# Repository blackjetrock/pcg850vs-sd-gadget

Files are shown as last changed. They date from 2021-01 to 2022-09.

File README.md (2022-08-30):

# pcg850vs-sd-gadget
Gadget for the PC-G850VS family of pocket computers

This gadget:

1. Reads SD card files into memory and then sends them to the PCG850VS
2. Captures data from the PCG850VS and allows it to be written to the SD card
3. Can scope the PIO mod eoutputs of the PC-G850VS

The PCB uses a blue pill as a processor, and an SD card module for the SD card functions. An OLED display allows operatin away from a computer.

Limitations:

The data sent or received is stored in the RAM of the blue pill, so no files greater than the available RAM can be sent or received. 
The SIO protocol has handshaking so this could be used to pause data from the PC-G850VS to the gadget when writing to the SD card. Reading from the card 
could be done without a problem as data is sent once it is read.

An ARM chip with more RAM could be fitted to the blue pill, this is more involved as it requires desoldering the QFP and putting a new one on.

An issue with early code meant that the SD card may not initialise properly. A code fix for this has bee pushed to the repository.

File Tags
---------

If the gadget detects a tag of '@file' (case sensitive) in the file that it has read from the G850 then it usd the filename specified after the tag
(delimited with a space) as the name to use if the file is written to the SD card. If the file tag does not exist then the gadget uses unique
filenames of the form PCGnnnn.DAT where nnnn is chosen to be the next unused value on the SD card.

Circuit
-------

The circuit uses a blue pill to do the processing. The PC-G850VS 11 pin interface is protected by series resistors. Power can come from either the blue pill or the PC-G850VS. If powered by the PC-G850VS short JP1. If you power the gadget from the blue pill when this is shorted then the 5V will be sent into the 5V of the 11 pin interface. I'm not sure what this will d, but it's probably not good.
There's an OLED display that is used to display menus. It is an I2C device. The SD card is held in a catalex SD card module, these are common on ebay.
Three keyswitches are used to control the menu system. As well as the OLED menus there are some commands that can be sent over the USB to serial connection. This needs a USB to serial adapter on J2.

The circuit involving Q1 is an inverter that should allow the UART functionality of the ARM processor to decode the serial data from the PC-G850VS. The current sketch does not use this but rather decodes the data stream using firmware.

For programming I use a STLINK V2 clone from ebay connected to the programming connector of the blue pill.

Construction Notes
==================

Components are fitted as shown on the schematic, apart from a few noted here:

The SD card reader module should be powered from 5V, not 3V3. The PCBs all have a 3V3 supply wired to the module. I have found that some modules will work with a 3V3 supply, but some won't. Cutting the track to the power pin of the module and running  wire from 3V3 to the supply pin of the module fixes the problem.

R14, Q1 and R15 are a hardware level shifter that takes the transmitted data (TX) from the PC-G850VS and sends it to the hardware USART on the blue pill. I don't use this at the moment as the code can decode the serial data. These components can be omitted or fitted. The sketch will have to be adjusted if you want to use the hardware USART.

J7 is a power jumper. If it is shorted then power comes from the PC-G850VS. If open then the blue pill can power the circuit (useful if programming the blue pill).
R4 and R5 are power connections and should be 0R links or wire links.

The blue pill, display and SD card reader can either be soldered to the PCB or fitted in sockets. If soldered then th eprofile is much lower but obviously these parts are harder to remve if you need to.

The SD card reader comes with a right angle type connector, for fitting on the PCB I desolder the connector it comes with and fit a straight connector.

I use a straight pin header for J1 and solder it on the top of the board. This is because straight headers are cheaper and they also lead to a lower profile once fitted.

OLED displays come in two pinouts, with reversed power connections. There's two connectors for the OLED display, one for each pinout. Make sure the OLED display is connected to the correct pinout connector.

I use an ST-LINKV2 from ebay for programming the blue pill. Any method of getting the sketch on to the blue pill should be fine.

Code
----

The menu structure that the code uses varies with the version of code that is running and th efunctions that are added to the code.
The menu option names have been elaborated from th ebasic names given in the instruction sheet, but it should be possible to work out 
which option does what.

Supported Devices
-----------------

The gadget has been used on the:
PC-G850VS
PC-G850

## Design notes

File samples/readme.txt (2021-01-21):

Sample Files
============

BASEN.BAS   This is the BASE-N program that executes when the BASE-N
            key is pressed.

picpro.asm  PIC program that runs on the prototype PCB and flashes the LED.

SCOPEDEMO.DAT A BASIC program that writes 0 to 255 to the PIO port. This
	      can be used to exercise the PIO scope option of the SD card
	      gadget. Set PIO mode and Scope PIO and then run this program.

ROMRD3.DAT    A BASIC program that attempts to read a 93C56 EEPROM.
	      Unfortunately it doesn't work.

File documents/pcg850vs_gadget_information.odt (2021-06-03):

Sharp PC-G850VS Gadget

# Overview

This gadget attached to the 11 pin socket on the PC-G850Vs and allows data sent over the serial data connection to be stored on SD cards. Files on the SD card can also be sent to the PC-G850VS. This provides a non-volatile storage system for the P-G850VS, and also a way to transfer files from a PC to the P-G850VS that doesn’t rely on a serial cable of some sort.

The PC-G850VS 11 pin connector is actually a versatile port that can operate in a number of modes. The gadget handles two of these modes:

SIO mode

PIO Mode

SIO mode is used for file transfer.

In PIO mode the gadget can display the state of the digital lines when set as outputs on the PC-G850VS as either a line graph or a number. To make some use of these signals, the firmware of the gadget would have to be adjusted. The soure code is available on GitHub.

There is an English manual available on the internet for the PC-G850VS, this contains information about the 11 pin interface.

# Gadget Hardware

The gadget is based around a ‘Blue Pill’ board. This is a small PCB with an STM32F103C8 microcontroller on it. It is programmed using the Arduino IDE. The STLINK V2 USB programming adapter is used to download code to the microcontroller.

Attached to the STM32F103C8 is an SD card adapter. The firmware reads and writes text to and from files on this SD card into a buffer in the microcontrollers RAM. This buffer of fixed size and this limits the largest file that can be transferred. This limit could be removed if the handshaking is enabled on the Sio interface, the code does not use this at present.

There is a small prototype area on the PCB that can be used to add hardware to the microcontroller, that can then be driven by the PC-G850.

An OLED display is used to display a menu system and also data from files and status messages.

Three buttons are used to control the menu and information screens. The red button is an ENTER, the black and white buttons are UP and DOWN.

# Jumper J7

The 11 pin interface can power the gadget, or it can be powered from the USB port on the Blue Pill. The best power option when attached to the PC-G850 is the 11 pin interface, there is no danger of feeding USB power into the 5V supply of the PC-G850, which could damage it, but this does put an extra load on the batteries in the PC-G850. Jumper J7 controls the connection of power to the gadget:

J7 with jumper in position: gadget powered from PC-G850

J7 with no jumper: gadget powered from Blue Pill USB

Do not operate the gadget with the USB attached and the jumper in position. This will connect the 5V from the Blue Pill to the 5V on the 11 pin interface and could damage the PC-G850.

# Gadget Firmware

The gadget firmware is in the github repository:

https://github.com/blackjetrock/pcg850vs-sd-gadget

It uses the Arduino IDE and framework. Programming is done using an STLINK V2 dongle attached to the programming connections on the Blue Pill. Power is not connected and the Blue Pill is powered from either the gadget or, preferable when programming, from USB. The STLINK V2 doesn’t have a large power supply capability and the gadget probably takes too much power when the OLED display is displaying a large number of pixels.

# Gadget Startup

On startup (or reset) the gadget checks the SD card and displays either ‘SD OK’ if a working card is found, or ‘SD Fail’ if no card is found. Obviously, if SD Fail is displayed then no files can be read or written, but all other functions will work.

# Gadget Menu

# Transferring a file to the SD card

The gadget is always ready to receive data from the 11 pin interface. Before sending a file to the gadget:

Put whatever file is required to be sent in the TEXT buffer. (This can be done using the TEXT mode options such as Basic->Text)

Set SIO mode on the gadget

(‘SIO’ menu option)

(‘Set SIO Mode’ menu option)

Clear the receive buffer in the gadget

(‘Clear’ menu option)

Set the correct SIO parameters in the PC-G850

These are:

(‘TEXT’ button)

(‘Sio’ option)

(‘Format’ option)

(‘baud rate’ 9600)

(‘data bit’ 8)

(‘stop bit’ 1)

(‘parity’ none)

(‘end of line’ CR LF)

(‘end of file’) 1A

(‘line number’ yes)

(‘flow’ none)

Use Sio menu to send the file

(‘TEXT’ button)

(‘Sio’ option)

(‘Save’ option)

When transfer completes, the contents of the buffer can be displayed

(‘Display’ menu option)

The bytes of the buffer should be displayed in ASCII and hex. UP and DOWN to page the data and the RED button to exit

Write the buffer to the SD card

(‘Write’ menu option)

The filenames are automatically chosen by the gadget. You can rename them in a computer if needed. The gadget doesn’t have the capability to rename files at present. The files are written to the root directory of the SD card.

The name of the file written and the number of bytes written are displayed for a few seconds

# Transferring a file from the SD card

Set SIO mode on the gadget

(‘SIO’ menu option followed by ‘Set SIO Mode’)

SIO mode only needs to be set once. It remains in force until another mode (such as PIO mode) is set.

List the files and select the one to send to the PC-G850.

(‘List’ menu option)

UP and DOWN are used to select the filename of the file to read. This menu option does not read the file, it just selects the file by name.

Clear the buffer

(‘Clear’ menu option)

Read the file

(‘Read’ menu option)

The name of the file and number of bytes read are dispolayed for a second or two. (There is a strange problem that sometimes happens whereby the number of byte read is 1. If this happens, read the file again).

Set the SIO parameters on the PC-G850 as above.

This only needs to be done once on the PC-G850, it retains SIO settings while off. A reset of the PC-G850 may reset the settings.

Set receive mode on the PC-G850

(‘TEXT’ button)

(‘Sio’ option)

(‘Load’ option)

Send the buffer

(‘Send’ menu option)

the file will transfer and the PC-G850 menu should change to the Sio menu. The file that was sent should now be in the TEXT buffer on the PC-G850

# Scoping the PIO outputs

Load the SCOPE.BAS example program into the PC-G850 TEXT buffer. This program counts in binary on the PIO outputs of the PC-G850.

Set PIO mode on the gadget, and GPIOs to all be inputs

(‘PIO’ menu option)

(‘PIO All Inputs’ menu option)

Enter run mode on the PC-G850

Select the Scope PIO menu option on the gadget just before RUNing the BASIC program.

(‘PIO’ menu option)

(‘Scope PIO’ menu option)

You should see the PIO lines counting in binary.

The RED button starts a new trace. There is no trigger facility and the GPIO lines are only sensed as high or low, not as analogue values. The UP and DOWN keys exit.

# Example Files

The githib repository has a directory that contains example files. If these are place don an SD card that is then inserted into the gadget, they can be used as a starting point for using the gadget.

# Supported Machines

I have used the gadget on these machines:

PC-G850VS

PC-G850V

It may work on other variants of the PC-G850 series, please let me know if you have tried other variants.

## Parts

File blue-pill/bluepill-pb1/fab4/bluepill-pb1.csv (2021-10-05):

Id | Designator | Package | Quantity | Designation | Supplier and ref
1 | J6 | PinHeader_1x06_P2.54mm_Vertical | 1 | Conn_01x06
2 | J7 | PinHeader_1x02_P2.54mm_Vertical | 1 | Conn_01x02
3 | R17,R16,R3,R2,R1 | R_Axial_DIN0207_L6.3mm_D2.5mm_P7.62mm_Horizontal | 5 | 4k7
4 | TP1 | TestPoint_Loop_D2.60mm_Drill0.9mm_Beaded | 1 | TestPoint
5 | R15,R14 | R_Axial_DIN0207_L6.3mm_D2.5mm_P7.62mm_Horizontal | 2 | R_Small
6 | U1 | BLUEPILL | 1 | BP
7 | SW2,SW3,SW1 | SW_PUSH-12mm | 3 | Switch_SW_SPST
8 | J5 | PinHeader_1x09_P2.54mm_Vertical | 1 | Conn_01x09
9 | Q1 | TO92_vert | 1 | Q_NPN_CBE
10 | J4,J2,J3 | PinHeader_1x04_P2.54mm_Vertical | 3 | Conn_01x04
11 | J1 | PinHeader_1x11_P2.54mm_Vertical | 1 | pc850vs_11_pin
12 | R13,R12,R11,R10,R9,R8,R7,R6,R5,R4 | R_Axial_DIN0207_L6.3mm_D2.5mm_P7.62mm_Horizontal | 10 | 1k
13 | A1 | SD_Card_Module | 1 | SD_Card_Module_catalex

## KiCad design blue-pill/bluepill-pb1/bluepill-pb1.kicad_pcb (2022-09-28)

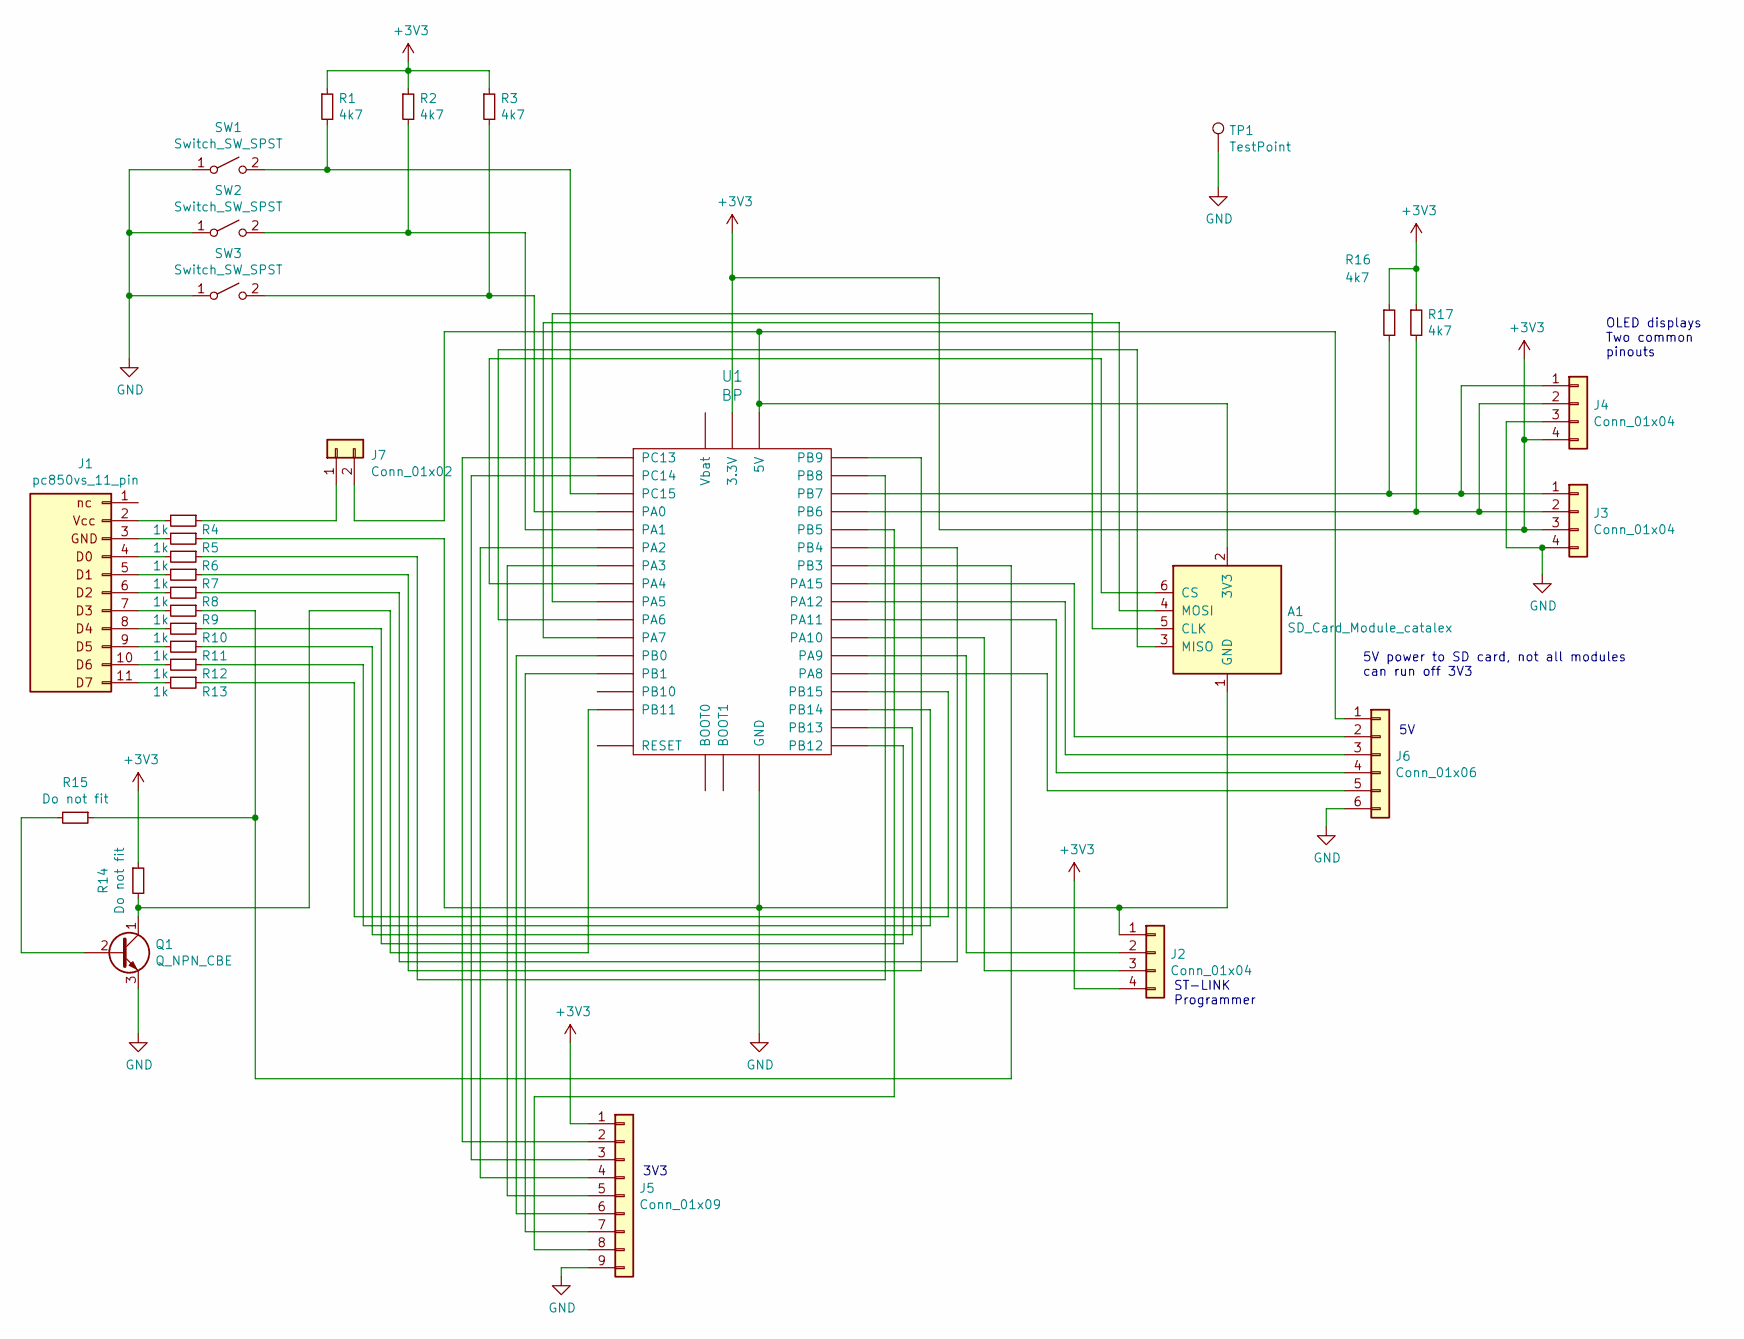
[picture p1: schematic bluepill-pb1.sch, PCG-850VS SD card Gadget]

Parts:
A1: SD_Card_Module_catalex; SD_Card_Module
J1: pc850vs_11_pin; PinHeader_1x11_P2.54mm_Vertical
J2, J3, J4: Conn_01x04; PinHeader_1x04_P2.54mm_Vertical
J5: Conn_01x09; PinHeader_1x09_P2.54mm_Vertical
J6: Conn_01x06; PinHeader_1x06_P2.54mm_Vertical
J7: Conn_01x02; PinHeader_1x02_P2.54mm_Vertical
Q1: Q_NPN_CBE; TO92_vert
R1, R2, R3, R16, R17: 4k7; R_Axial_DIN0207_L6.3mm_D2.5mm_P7.62mm_Horizontal
R4, R5, R6, R7, R8, R9, R10, R11, R12, R13: 1k; R_Axial_DIN0207_L6.3mm_D2.5mm_P7.62mm_Horizontal
R14, R15: Do not fit; R_Axial_DIN0207_L6.3mm_D2.5mm_P7.62mm_Horizontal
SW1, SW2, SW3: Switch_SW_SPST; SW_PUSH-12mm
TP1: TestPoint; TestPoint_Loop_D2.60mm_Drill0.9mm_Beaded
U1: BP; BLUEPILL

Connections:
+3V3: J2.4, J3.3, J4.4, J5.1, R1.1, R2.1, R3.1, R14.1, R16.1, R17.1, U1.3V3 (3.3V)
GND: A1.1 (GND), J2.1, J3.4, J4.3, J5.9, J6.6, Q1.3 (E), R5.1, SW1.1 (A), SW2.1 (A), SW3.1 (A), TP1.1, U1.G (GND)
unnamed: A1.2 (3V3), J6.1, J7.2, U1.5V
unnamed: A1.3 (MISO), U1.PA6
unnamed: A1.4 (MOSI), U1.PA7
unnamed: A1.5 (CLK), U1.PA5
unnamed: A1.6 (CS), U1.PA4
unnamed: J1.2 (+5V), R4.2
unnamed: J1.3 (GND), R5.2
unnamed: J1.4 (D0), R6.2
unnamed: J1.5 (D1), R7.2
unnamed: J1.6 (D2), R8.2
unnamed: J1.7 (D3), R9.2
unnamed: J1.8 (D4), R10.2
unnamed: J1.9 (D5), R11.2
unnamed: J1.10 (D6), R12.2
unnamed: J1.11 (D7), R13.2
unnamed: J2.2, U1.PA9
unnamed: J2.3, U1.PA10
unnamed: J3.1, J4.1, R16.2, U1.PB7
unnamed: J3.2, J4.2, R17.2, U1.PB6
unnamed: J5.2, U1.PC13
unnamed: J5.3, U1.PC14
unnamed: J5.4, U1.PA2
unnamed: J5.5, U1.PA3
unnamed: J5.6, U1.PB0
unnamed: J5.7, U1.PB1
unnamed: J5.8, U1.PB5
unnamed: J6.2, U1.PA15
unnamed: J6.3, U1.PA12
unnamed: J6.4, U1.PA11
unnamed: J6.5, U1.PA8
unnamed: J7.1, R4.1
unnamed: Q1.1 (C), R14.2, U1.PB11
unnamed: Q1.2 (B), R15.2
unnamed: R1.2, SW1.2 (B), U1.PC15
unnamed: R2.2, SW2.2 (B), U1.PA1
unnamed: R3.2, SW3.2 (B), U1.PA0
unnamed: R6.1, U1.PB8
unnamed: R7.1, U1.PB9
unnamed: R8.1, U1.PB4
unnamed: R10.1, U1.PB12
unnamed: R11.1, U1.PB13
unnamed: R12.1, U1.PB14
unnamed: R13.1, U1.PB15
unnamed: R9.1, R15.1, U1.PB3

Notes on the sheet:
ST-LINK Programmer
OLED displays Two common pinouts
3V3
5V power to SD card, not all modules can run off 3V3

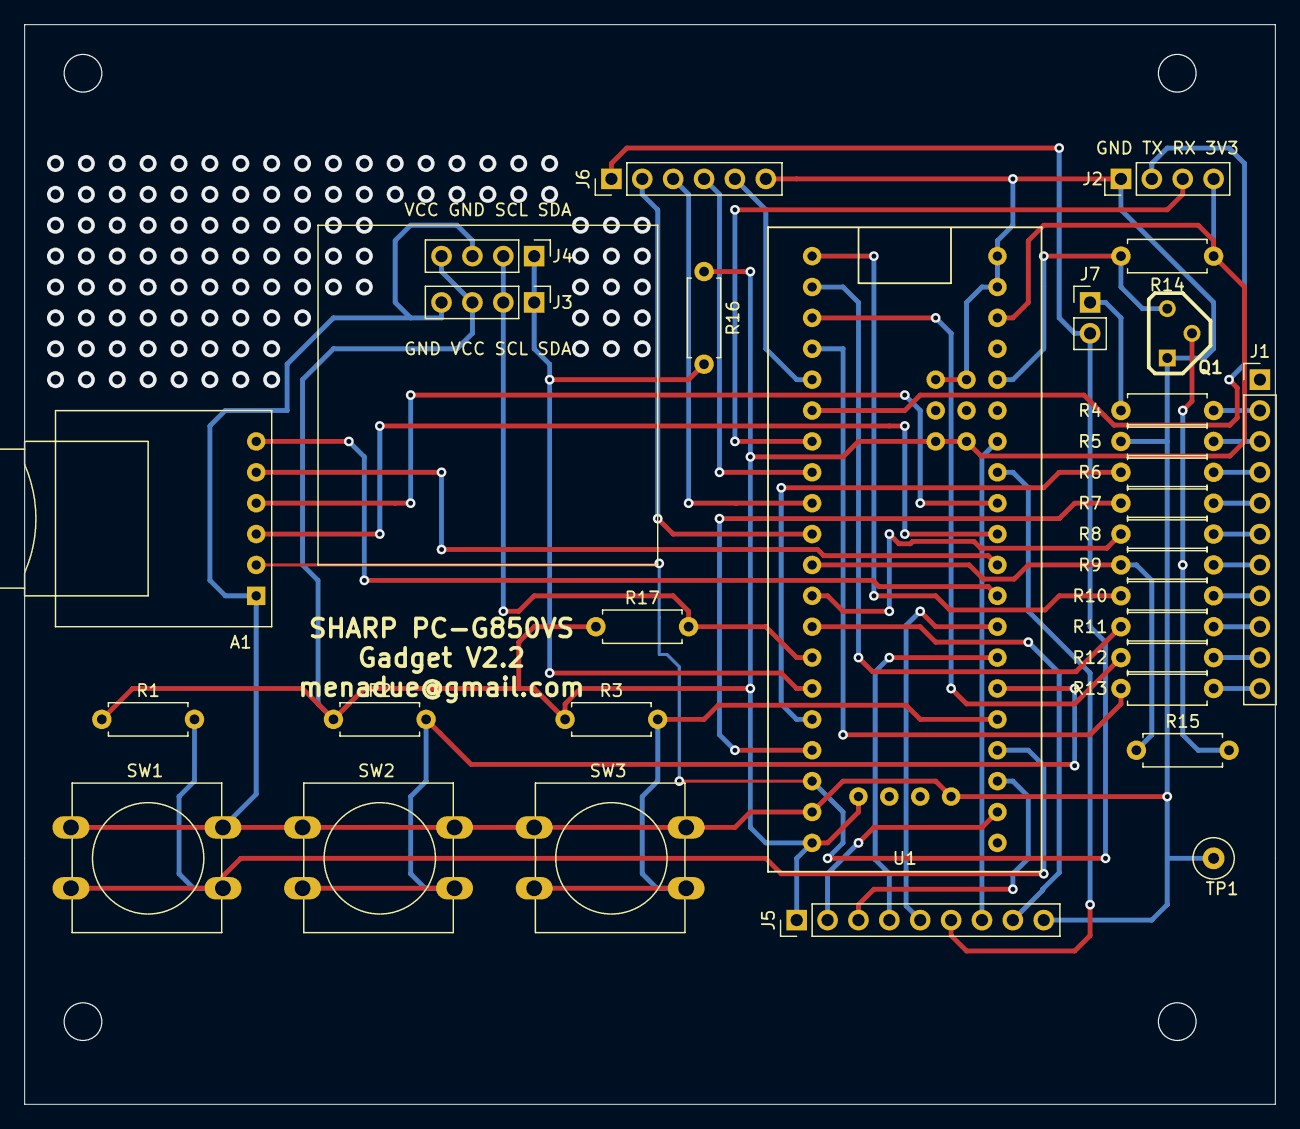
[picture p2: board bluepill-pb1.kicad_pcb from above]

Board: 2 copper layers, 102.9 x 88.8 mm, 31 parts (0 on the bottom side), 46 nets.

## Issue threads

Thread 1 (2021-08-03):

Would like to buy a build of this device

phoenixx100, 2021-08-03:
Am _very_ interested in purchasing a build of this useful device for a reasonable price, because I lack the hardware construction skills.

Please, contact me at:

phoenixx100 (at) hotmail.com

blackjetrock, 2021-08-03:
Hello,

I have just ordered a set of PCBs which should arrive in a couple of weeks
or so. I have a set of documents about the gadget and other bits and bobs.
Due to the current shipping situation I only ship using a tracked service.

Regards

Andrew Menadue

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

phoenixx100, 2021-08-03:
Thanks for your swift reply. Good to hear that you are planning on creating some more of them. What would you be charging for one? Also, would you want my payment in advance?

________________________________
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

blackjetrock, 2021-08-03:
Hi,
An assembled gadget is £27 plus shipping, which is tracked. If you are
interested then I'll build the gadget and then we can arrange payment
including shipping, so no payment until I have a gadget built and ready to
ship.

Regards

Andrew Menadue

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

phoenixx100, 2021-08-03:
Excellent...

I have just today ordered a SHARP PC-G850VS. It will be coming from Japan, so it will surely take some time to arrive here in Chicago. I'm an oldskool 1980s programmer (mostly BASIC and similar languages) and am really interested in learning C and the Assembly languages offered on the PC-G850VS. Having such a small 32K memory, it is unthinkable to begin using it for serious purposes without some sort of mass storage solution.

I am very much looking forward to purchasing and utilizing your device.

Terry

________________________________
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

blackjetrock, 2021-08-07:
Hi,

I have built a gadget for you. I saw that you are in Chicago so worked out
shipping, which is £13. Obviously I'll need a more targeted address than
Chicago!

Regards

Andrew Menadue

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

blackjetrock, 2021-08-07:
Hi,

I have built a gadget for you. I saw that you are in Chicago so worked out
shipping, which is £13. Obviously I'll need a more targeted address than
Chicago!

Regards

Andrew

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

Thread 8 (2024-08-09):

Can you please help? Can you help me when I get the above error when compiling with Arduino?

chunmingwen, 2024-08-09:
Arduino:1.8.19 (Windows 7), 開發板:"Generic STM32F1 series, BlackPill F103C8, STM32CubeProgrammer (SWD), Enabled (generic 'Serial'), None, Low/Full Speed, Smallest (-Os default), None, Newlib Nano (default)"

In file included from C:\Program Files (x86)\Arduino\libraries\Adafruit_Circuit_Playground/utility/CP_Firmata.h:17,

                 from C:\Program Files (x86)\Arduino\libraries\Adafruit_Circuit_Playground/Adafruit_Circuit_Playground.h:25,

                 from C:\Program Files (x86)\Arduino\libraries\Adafruit_Circuit_Playground/Adafruit_CircuitPlayground.h:3,

                 from C:\Users\wencm\Downloads\pcg850vs-sd-gadget-main\pcg850vs_gadget_1\pcg850vs_gadget_1.ino:7:

C:\Program Files (x86)\Arduino\libraries\Adafruit_Circuit_Playground/utility/CP_Boards.h:746:2: error: #error "Please edit CP_Boards.h with a hardware abstraction for this board"

  746 | #error "Please edit CP_Boards.h with a hardware abstraction for this board"

      |  ^~~~~

exit status 1

開發板 Generic STM32F1 series 編譯錯誤。

This report would have more information with
"Show verbose output during compilation"
option enabled in File -> Preferences.

blackjetrock, 2024-08-10:
Hello,
I don't use windows at all, in fact I don't have a windows machine. It may
be that you are attempting to compile with the wrong libraries, can you
check you are using the correct libraries, in that they match the ones I
used ?
Your error looks a bit like you haven't set up the cp_boards.h file for the
blue pill stm32f103c8?

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

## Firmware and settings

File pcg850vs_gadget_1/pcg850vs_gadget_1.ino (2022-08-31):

////////////////////////////////////////////////////////////////////////////
// pcg850vs_gadget_1_Rev_B_v1_2_SBH
//
// Based on https://github.com/blackjetrock/pcg850vs-sd-gadget
// 
// Modified: SBH 04/08/22   v1.0   Added comments
//           SBH 05/08/22   v1.1   Removed surplus code, added transmit status graph
//           SBH 05/08/22   v1.2   Blinking cursor    case TRANSFER_PCU:
//           AJM 21/08/22   v2.0   Merged SBH code, altered version and put back in menu options
//           AJM 22/08/22   v2.1   Tidied version string and menu
//           AJM 27/08/22   v2.2   Added SSIO reception interrupt. Temp comment out due to menu scrolling
//                                 not working.
//           AJM 28/08/22   v2.3   Added 'Send File' menu option. This sends the file data directly from an
//                                 SD card file so has no buffer involved and hence no length limit.
//                                 Re-arranged menus so they always fit on a screen.
//           AJM 31/08/22   v2.4   Has fixed menu scrolling and start of extra modes for data
//                                 transfer
//                                 Added status line
////////////////////////////////////////////////////////////////////////////////////////////////////
//
// ARDUINO IDE SETTINGS
// Board:          Generic STM32F1 Series
// Board Part No.: BlackPill F103C8
// Upload method:  STM32CubeProgrammer (SWD)
// Preferences -> Additional Boards Manager URL: https://github.com/stm32duino/BoardManagerFiles/raw/main/package_stmicroelectronics_index.json
//
///////////////////////////////////////////////////////////////////////////

#define VERSION_STRING "V2.4"

#include <SPI.h>
#include <SD.h>
#include <Wire.h>
#include <Adafruit_GFX.h>
#include <Adafruit_SSD1306.h>

#define SCREEN_WIDTH 128 // OLED display width, in pixels
#define SCREEN_HEIGHT 64 // OLED display height, in pixels

// Declaration for an SSD1306 display connected to I2C (SDA, SCL pins)
#define OLED_RESET     4 // Reset pin # (or -1 if sharing Arduino reset pin)
Adafruit_SSD1306 display(SCREEN_WIDTH, SCREEN_HEIGHT, &Wire, OLED_RESET);

#define ACK1  1
#define ACK2  0       // Works with PCG850

////////////////////////////////////////////////////////////////////////////////////////////////////
//
// Define variables
//
////////////////////////////////////////////////////////////////////////////////////////////////////

int loop_loops = 0;

Sd2Card card;
SdVolume volume;
SdFile root;

int filename_index = 0;

const int chipSelect = 4;

// Pins for Sharp 11 pin interface data lines
const int IFD0Pin  = PB8;
const int IFD1Pin  = PB9;
const int IFD2Pin  = PB4;
const int IFD3Pin  = PB3;
const int IFD4Pin  = PB12;
const int IFD5Pin  = PB13;
const int IFD6Pin  = PB14;
const int IFD7Pin  = PB15;

// SIO pins
const int SIORTSPin = IFD0Pin;
const int SIODTRPin = IFD1Pin;
const int SIORXDPin = IFD2Pin;
const int SIOTXDPin = IFD3Pin;
const int SIOCDPin  = IFD4Pin;
const int SIOCTSPin = IFD5Pin;
const int SIODSRPin = IFD6Pin;
const int SIOCIPin  = IFD7Pin;

// SSIO pins
const int SIOBUSYPin = IFD0Pin;
const int SIODOUTPin = IFD1Pin;
const int SIOXINPin  = IFD2Pin;
const int SIOXOUTPin = IFD3Pin;
const int SIODINPin  = IFD4Pin;
const int SIOACKPin  = IFD5Pin;
const int SIOEX1Pin  = IFD6Pin;
const int SIOEX2Pin  = IFD7Pin;

// Debug outputs
const int statPin   = PC13;
const int dataPin   = PC14;


#define NIF 8

const int if_pin[NIF] = {
  IFD0Pin,
  IFD1Pin,
  IFD2Pin,
  IFD3Pin,
  IFD4Pin,
  IFD5Pin,
  IFD6Pin,
  IFD7Pin,
};
  
File myFile;

// Capture file
File dumpfile;


#define DEBUG_SERIAL 0
#define DIRECT_WRITE 0

// STM32F103C8 has only 20k of SRAM
//const int MAX_BYTES = 10000;
const int MAX_BYTES = 10000; 
const int button1Pin = PA0;
const int button2Pin = PA1;
const int button3Pin = PC15;

typedef unsigned char BYTE;

typedef void (*FPTR)();
typedef void (*CMD_FPTR)(String cmd);

#define NUM_BUTTONS 3

// Debounce
#define MAX_BUT_COUNT 6

int but_pins[NUM_BUTTONS] = {button1Pin, button2Pin, button3Pin};

typedef struct _BUTTON
{
  int     count;
  boolean pressed;
  boolean last_pressed;   // For edge detection
  FPTR    event_fn;
} BUTTON;

BUTTON buttons[NUM_BUTTONS];

enum ELEMENT_TYPE
  {
    BUTTON_ELEMENT = 10,
    SUB_MENU,
    MENU_END,
  };

struct MENU_ELEMENT
{
  enum ELEMENT_TYPE type;
  char *text;
  void *submenu;
  void (*function)(struct MENU_ELEMENT *e);
};


struct MENU_ELEMENT *current_menu;
struct MENU_ELEMENT *last_menu;
struct MENU_ELEMENT *the_home_menu;

unsigned int menu_selection = 0;
unsigned int menu_size = 0;
unsigned int top_scroll = 0;

#define MENU_TOP_LINE 1
#define MAX_LISTFILES 7
#define MAX_NAME      20

const char *filetag = "@file ";

MENU_ELEMENT listfiles[MAX_LISTFILES+1];
int num_listfiles;
char names[MAX_LISTFILES][MAX_NAME];
char selected_file[MAX_NAME+1];
char current_file[MAX_NAME+1];
char current_rx_file[MAX_NAME+1];

// Where the received data goes
char stored_bytes[MAX_BYTES] = "Test data example. 01234567890";

int stored_bytes_index = 0;

// How many bytes in the buffer. We have a default for testing without a Microtan
int bytecount = 24;

////////////////////////////////////////////////////////////////////////////////////////////////////
//
// communication with ISRs
//
////////////////////////////////////////////////////////////////////////////////////////////////////

volatile int data_byte;
volatile int bit_count;
volatile int got_byte = 0;
volatile int state = 0;
volatile int data_bit = 2;

// We build the byte packet in this int, it can be longer than
// 8 bits as it has th estart bit, stop bit and parity if we have it on

volatile unsigned int capture_bits_len = 0;
volatile unsigned int capture_bits = 0xffff;

// Flag that indicates we are looking for a start bit
volatile int waiting_for_start = 1;

#define START_BIT 2

// Flag that indicates we have a bit or bits. This indicates activity on the serial
// line that may need to be attended to
volatile int got_bit = 0;

// How many bits we have received
volatile int number_of_bits = 0;

// Bit value of the N bits
volatile int bit_value = 0;

// Bit period in us
// default to 9600
//volatile int bit_period = 833;
volatile int bit_period = 102;

////////////////////////////////////////////////////////////////////////////////////////////////////
//
// What type of transfer protocol are we currently set up to use?
//
////////////////////////////////////////////////////////////////////////////////////////////////////

enum TRANSFER_TYPE
  {
    TRANSFER_SIO = 20,
    TRANSFER_SSIO,
    TRANSFER_PCU,
    TRANSFER_PIO,
    TRANSFER_NONE,
  };

enum TRANSFER_TYPE transfer_type = TRANSFER_NONE;

////////////////////////////////////////////////////////////////////////////////////////////////////
//
// Define prototypes
//
////////////////////////////////////////////////////////////////////////////////////////////////////

void but_ev_null();
void but_ev_up();
void but_ev_down();
void but_ev_select();
void button_ssio_mode();


void send_serial_byte(int byte)
{
  int j;
  
  // Start bit
  digitalWrite(SIORXDPin, HIGH);
  delayMicroseconds(bit_period);
  
  // Now 8 data bits, LS first
  for(j=0; j<8; j++)
    {
      if( byte & 1 )
	{
	  digitalWrite(SIORXDPin, LOW);
	  delayMicroseconds(bit_period);
	}
      else
	{
	  digitalWrite(SIORXDPin, HIGH);
	  delayMicroseconds(bit_period);
	}
      
      byte >>= 1;
    }
  
  // Stop bit
  digitalWrite(SIORXDPin, LOW);
  delayMicroseconds(bit_period);
  
  // Put a little character delay in
  delayMicroseconds(10*bit_period);
  
}

////////////////////////////////////////////////////////////////////////////////////////////////////
//
// Sends a file 
//
////////////////////////////////////////////////////////////////////////////////////////////////////

// This sends a file from SD card to the 850. The buffer is not used, so any size file should
// be handled fine, assuming the 850 can receive it

void send_file(boolean oled_nserial)
{
  int i, j;
  int bytecount = 0;
  String fullBarGraph = "************************";
  int byte_sent;
  
  if( oled_nserial )
    {
      display.clearDisplay();
      display.setCursor(0,0);
      display.println("Sending file ");
      display.println(current_file);
      display.display();
      delay(1000);
    }
  else
    {
      Serial.print("Sending file '");
      Serial.print(current_file);
      Serial.println("'");
    }
  
  myFile = SD.open(current_file);
  
  if (myFile)
    {
      // Read through to find size of file
      while (myFile.available())
	{
	  myFile.read();
	  bytecount++;
	}

      // close the file:
      myFile.close();

      // and re-open
      myFile = SD.open(current_file);

      i = 0;
      
      // Read from the file and send it
      while (myFile.available())
	{
	  byte_sent = myFile.read();	  

	  send_serial_byte(byte_sent);
	  i++;
	  
	  // Bar graph status update
	  if( oled_nserial )
	    {
	      display.clearDisplay();
	      display.setCursor(0,0);
	      display.println(fullBarGraph.substring(0, int(20*i/bytecount)));
	      display.setCursor(0,20);
	      display.print(i);
	      display.print(" of ");
	      display.print(bytecount);
	      display.print(" bytes");
	      display.display();
	    }
	  else
	    {
	      Serial.print(i);
	    }
	}
      
      // close the file:
      myFile.close();

      // Add end of file marker if it wasn't the last character sent
      if( byte_sent != 0x1a )
	{
	  send_serial_byte(0x1a);
	}
      
      if( oled_nserial )
	{
	  display.clearDisplay();
	  display.setCursor(0,0);
	  display.println("Done.");
	  display.display();
	  delay(1000);
	}
      else
	{
	  Serial.println("Done");
	}
    }
  else
    {
      // if the file didn't open, print an error:
      if( oled_nserial )
	{
	  display.println("Error opening");
	  display.println(current_file);
	  display.display();
	  delay(1000);
	}
      else
	{
	  Serial.print("Error opening ");
	  Serial.println(current_file);
	}
    }
}



////////////////////////////////////////////////////////////////////////////////////////////////////
//
// Sends the currently loaded data bytes to the PC-G850 using the currently
// set bit period (baud rate)
//
// Signals are all inverted, so start bit is HIGH (logical 0)
// Data transmitted LS first, 8N1 is format
// We add a 0x1a to the end as an end of file marker
//
////////////////////////////////////////////////////////////////////////////////////////////////////

void send_databytes(boolean oled_nserial)
{
  int i, j;
  int byte;
  String fullBarGraph = "************************";

  // Add end of file marker if there isn't one
  if( stored_bytes[bytecount-1] != 0x1a )
    {
      stored_bytes[bytecount++] = 0x1a;
    }

  if( oled_nserial )
    {
      display.clearDisplay();
      display.setCursor(0,0);
      display.println("Sending ");
      display.println(bytecount);
      display.println(" bytes");
      display.display();
      delay(1000);
    }
  else
    {
      Serial.print("Sending ");
      Serial.print(bytecount);
      Serial.println(" bytes");
    }

  // Send byte
  for(i=0; i<bytecount; i++)
    {
      // Send one byte
      byte = stored_bytes[i];

      // Start bit
      digitalWrite(SIORXDPin, HIGH);
      delayMicroseconds(bit_period);

      // Now 8 data bits, LS first
      for(j=0;j<8;j++)
	{
	  if( byte & 1 )
	    {
	      digitalWrite(SIORXDPin, LOW);
	      delayMicroseconds(bit_period);
	    }
	  else
	    {
	      digitalWrite(SIORXDPin, HIGH);
	      delayMicroseconds(bit_period);
	    }

	  byte >>= 1;
	}

      // Stop bit
      digitalWrite(SIORXDPin, LOW);
      delayMicroseconds(bit_period);

      // Put a little character delay in
      delayMicroseconds(10*bit_period);

      // Bar graph status update
      if( oled_nserial )
          {
            display.clearDisplay();
            display.setCursor(0,0);
            display.println(fullBarGraph.substring(0, int(20*i/bytecount)));
            display.setCursor(0,20);
            display.print(i);
            display.print(" of ");
            display.print(bytecount);
            display.print(" bytes");
            display.display();
          }
        else
          {
            Serial.print(i);
          }
    }
//

    if( oled_nserial )
    {
      display.clearDisplay();
      display.setCursor(0,0);
      display.println("Done.");
      display.display();
      delay(1000);
    }
  else
    {
      Serial.println("Done");
    }
}


////////////////////////////////////////////////////////////////////////////////////////////////////
//
// Set 11 pin interface pins to inputs. This is the safest state we can be in
//
////////////////////////////////////////////////////////////////////////////////////////////////////

void set_if_inputs()
{
  int i;
  for(i=0; i<NIF; i++)
    {
      pinMode(if_pin[i], INPUT);
    }
  
}

////////////////////////////////////////////////////////////////////////////////////////////////////
//
// 
//
////////////////////////////////////////////////////////////////////////////////////////////////////


// Set interface to SIO mode

void set_if_sio()
{
  set_if_inputs();
}

// Set interface to SSIO mode

void set_if_ssio()
{
  set_if_inputs();

  // Set up control lines to allow 850 to send and receive
  // SSIO data
  
  pinMode(SIOBUSYPin, INPUT);
  pinMode(SIODOUTPin, INPUT);
  pinMode(SIOXOUTPin, INPUT);
  
  pinMode(SIODINPin,  INPUT);
  //  digitalWrite(SIODINPin, LOW);
  pinMode(SIOXINPin,  OUTPUT);
  digitalWrite(SIOXINPin, LOW);

  // Drive signals to allow sending by 850
  digitalWrite(SIOACKPin, LOW);    // Wait

  pinMode(SIOACKPin,  OUTPUT);

  // Drive signals to allow sending by 850

  digitalWrite(SIOACKPin, LOW);

  //detachInterrupt(digitalPinToInterrupt(SIOTXDPin));
  //attachInterrupt(digitalPinToInterrupt(SIOXOUTPin), ssio_isr,  RISING);
  
}

void set_if_pcu(void)
{
  set_if_ssio();
}


// Read the state of the interface
int read_if_state()
{

  int i;
  int val = 0;
  
  for(i=NIF-1; i>=0; i--)
    {
      val *=2;
      val += digitalRead(if_pin[i]);
    }
  return(val);
}

//
// Allow interaction with serial monitor
//

// Commands
int indx = 0;


////////////////////////////////////////////////////////////////////////////////////////////////////
//
// 
//
////////////////////////////////////////////////////////////////////////////////////////////////////

void cmd_next(String cmd)
{
  indx++;
}

////////////////////////////////////////////////////////////////////////////////////////////////////
//
// 
//
////////////////////////////////////////////////////////////////////////////////////////////////////


void cmd_prev(String cmd)
{
  indx--;
}


////////////////////////////////////////////////////////////////////////////////////////////////////
//
// 
//
////////////////////////////////////////////////////////////////////////////////////////////////////

void cmd_index(String cmd)
{
  String arg;
  
  Serial.println("INDEX");
  arg = cmd.substring(1);
  Serial.println(arg);
  
  indx = arg.toInt();
}



////////////////////////////////////////////////////////////////////////////////////////////////////
//
// Modify the buffer
//
////////////////////////////////////////////////////////////////////////////////////////////////////

void cmd_modify(String cmd)
{
  String arg;
  
  Serial.println("MOD");
  arg = cmd.substring(1);

  if( indx <= MAX_BYTES )
    {
      stored_bytes[indx] = arg.toInt();
    }
}

#define DISPLAY_COLS 16


////////////////////////////////////////////////////////////////////////////////////////////////////
//
// Displays the file data, with offset and address (from start address stored in file data)
//
////////////////////////////////////////////////////////////////////////////////////////////////////

void cmd_display(String cmd)
{
  int i;
  int address = stored_bytes[10]*256+stored_bytes[11]-12;
  
  char ascii[DISPLAY_COLS+2];
  char c[2];
  char line[50];
  
  int ascii_i = 0;
  ascii[0] ='\0';
  
  Serial.print("Byte Count:");
  Serial.print(bytecount);
  Serial.print("  Index:");
  Serial.println(indx);

  for(i=0; i<bytecount; i++)
    {
      if( (i%DISPLAY_COLS)==0 )
	{
	  sprintf(line, "%s\n%04X %04X:", ascii, i, address); 	  
	  Serial.print(line);
	  ascii_i = 0;
	}

      sprintf(line, "%02X ", stored_bytes[i]);
      Serial.print(line);
      
      if( isprint(stored_bytes[i]) )
	{
	  sprintf(c, "%c", stored_bytes[i]);
	}
      else
	{
	  c[0] ='.';
	}
      ascii[ascii_i++] = c[0];
      ascii[ascii_i] = '\0';
      
      address++;
    }

  ascii[ascii_i++] = '\0';

  // Pad to the ascii position
  for(i=ascii_i-1; i<DISPLAY_COLS; i++)
    {
      Serial.print("   ");
    }
  
  Serial.print(ascii);
  Serial.print(" ");
  Serial.println("");
}


////////////////////////////////////////////////////////////////////////////////////////////////////
//
// Clear the buffer
//
////////////////////////////////////////////////////////////////////////////////////////////////////

void cmd_clear(String cmd)
{
  bytecount = -1;    // We reset to -1 so we drop the leading spurious character

#if DIRECT_WRITE
  SD.remove(filename);
  dumpfile = SD.open("dumpfile.bin", FILE_WRITE);
#endif
  
}

////////////////////////////////////////////////////////////////////////////////////////////////////
//
// Close the capture file
//
////////////////////////////////////////////////////////////////////////////////////////////////////

void cmd_close(String cmd)
{
  dumpfile.close();
}

////////////////////////////////////////////////////////////////////////////////////////////////////
//
// 
//
////////////////////////////////////////////////////////////////////////////////////////////////////
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
void loop() {
  char c;

  // Update the button state
  update_buttons();

  // Run the serial monitor
  run_monitor();

  if( Serial2.available(),0 )
    {
      c = Serial2.read();
      Serial.print(" S");
      Serial.println(c,HEX); 
    }

  // Run a task that handles flow control on the data coming in to us
  //flow_control_task();

  // Display periodic status
  if( loop_loops == 1000 )
    {
      display_status_line();
      loop_loops = 0;
    }
  
  loop_loops++;
}


////////////////////////////////////////////////////////////////////////////////////////////////////
//
// The ISRs look at edges on the TXD line. The delays between the edges are
// processed to get the data stream.
// 
// This is called when a falling edge is detected on the TXD pin
// Despite the interrupt funtion name, this is now called on both rising and falling edges
//
////////////////////////////////////////////////////////////////////////////////////////////////////

volatile long t, t2 = 0;
long delta = 0;
volatile long hz2400=0, hz1200=0;
int in_byte = 0;

void lowISR()
{
  // Debug
  // This line indicates when a n interrupt is running. 
  digitalWrite(statPin, HIGH);

  // If the TXD line is now high then it was a period of zeros, but as the TXD line is inverted
  // that means it was a period of ones
  
  if ( digitalRead(SIOTXDPin) == HIGH )
    {
      digitalWrite(dataPin, HIGH);
      digitalWrite(dataPin, LOW);
      digitalWrite(dataPin, HIGH);
      digitalWrite(dataPin, LOW);

      bit_value = 1;
    }
  else
    {
      digitalWrite(dataPin, HIGH);
      digitalWrite(dataPin, LOW);
      bit_value = 0;
    }

  // Get the delta
  t = micros();
  delta = t - t2;
  t2 = t;
  
  int i;
  
  // We now have N bits, we can work out how many by dividing the
  // delta by the bit time which is set up by the main code
  // Limit the number of bits we process so we don't have large startup delays
#define BIT_LIMIT 20
  
  if( delta > bit_period * BIT_LIMIT )
    {
      delta = bit_period * BIT_LIMIT;
    }
  else
    {
      number_of_bits = (delta+bit_period/2) / bit_period;
    }
  
  // Add some bits to the bit stream
  for(i=0; i<number_of_bits; i++)
    {
      // Shift one bit in to 'capture_bits' which is a window that we use to process
      // the bits as they arrive

      // Shift data in to the top bit position
      capture_bits = capture_bits >> 1;
      capture_bits += bit_value<<15;
      
      // One more bit
      capture_bits_len++;
      
      // The window looks like this (we use 8n1 format only)
      //
      //  SDDD DDDD DT.. ....
      //
      //  S: Start bit
      //  D:Data bit of 8 bits long byte
      //  T: Stop bit
      //  .: Following bits, we don't care about these at the moment
      //
      // Check for a frame, this is a start bit (1), 8 data bits and a stop bit
      // which is 1DDD DDDD D0xx xxxx
      // To check framing we use a mask of 0x8040, if the value we get is
      // 0x8000 then we have a start bit of 1 and a stop bit of 0, which is a frame
      
      if( (capture_bits & 0x8040) == 0x8000 )
	{
	  // We have a frame	  
	  // Extract the data byte from the window
	  
	  stored_bytes[bytecount++] = (capture_bits & 0x7f80) >> 7;

	  // We store the data bytes in a buffer and that has a maximum size. If we reach that
	  // size then we discard the data
	  
	  if ( bytecount >= MAX_BYTES )
	    {
	      bytecount = MAX_BYTES -1;
	    }

	  // Every 500 bytes we display a status message
	  if( (bytecount % 500) == 0 )
	    {
	      Serial.print(bytecount);
	      Serial.println(" bytes");
	    }
#if 1
	  //Serial.print(".");
#else
	  
	  Serial.print(capture_bits, HEX);

	  Serial.print(" ");
	  Serial.print(stored_bytes[bytecount-1], HEX);

	  
	  if ( (bytecount % 16) == 0)
	    {
	      Serial.println("");
	    }
#endif

	  // Blank out the byte we just received by replacing the bits of that frame with the
	  // start bit line state. As the stop bit value is 0 the data byte detetion code above will not
	  // see a data byte until the stop bit is received, which is a 0
	  capture_bits = 0xffff;
	}
      
      // Signal we have a bit or bits
      got_bit = 1;
    }

  // Debug
  digitalWrite(statPin, LOW);
}

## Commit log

2020-10-09 Created files for public repository
    [bluepill-pb1-B_Cu.gbr, bluepill-pb1-B_Mask.gbr, bluepill-pb1-B_Paste.gbr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]
2020-11-07 Update README.md
    Added SD module power supply problem to construction notes.
2021-01-21 Added samples
    [bluepill-pb1-B_Cu.gbr, bluepill-pb1-B_Mask.gbr, bluepill-pb1-B_Paste.gbr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]
2021-07-09 Added component values
    [bluepill-pb1.sch]
2021-10-05 Fix to issue #2
    The SD card would sometimes not initialise. A possible fix to this is in this
    commit.
    By putting a finger on various terminals I found that the CS pin of the SD card adapter
    could stop initialisation of the card if it was held high. Holding it low with a high-ish
    resistance allowed the SD card to initialise every time. With the theory that the CS line
    was activating before or during the SD card initialisation and messing it up, holding it low with a resistor
    would deselect it unless the blue pill drove the GPIO high when it wanted ot send a command
    or data.
    As a test, I have added an explicit GPIO output data direction setup and drive the GPIo to 0 as early
    as possible. This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
    [bluepill-pb1.csv, bluepill-pb1.kicad_pcb, bluepill-pb1.sch]
2021-10-07 Refined button event trigger
2021-10-07 Implemented the first cut of file name annotation
2021-11-04 Fixed the buffer offset issue after SIO made active
    [pcg850vs_gadget_1.ino]
2022-08-27 Added a mode that can receive SSIO (CE-126) data. This means that you can do LPRINT or LLIST and get that data sent to the buffer. Temporarily commented out as the extra menu item fills the screen an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
    [pcg850vs_gadget_1.ino]
2022-08-30 Re-arranged menus a bit to make room for new SSIO and PCU menus.
    Fixes:
    1. Menus can now scroll like the file name display
    2. SSIO menu added. This works with the PCG850VS when it has done an OPEN("LPRT:") and then issues
    an LPRINT, LFILES or LLIST command. The output is sent to the gadget.
    SSIO mode is not on th eother Sharp pocket computers, they use the PCU protocol below
    3. Added a PCU (Printer Control Unit) protocol which is designed to appear as a CE-126 printer/cassette
    unit. This version of that code does not work.
    [pcg850vs_gadget_1.ino]
2022-08-31 Added a status line at the top of the OLED screen. This shows the current number of bytes in the buffer at the left and the current transfer protocol at the right. This is in preparation for the diff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
    [pcg850vs_gadget_1.ino]
2022-09-28 Added PCB V2.2, which fixes the wire needed on V2.1
    [bluepill-pb1-B_Cu.gbr, bluepill-pb1-B_Mask.gbr, bluepill-pb1-B_Paste.gbr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]
